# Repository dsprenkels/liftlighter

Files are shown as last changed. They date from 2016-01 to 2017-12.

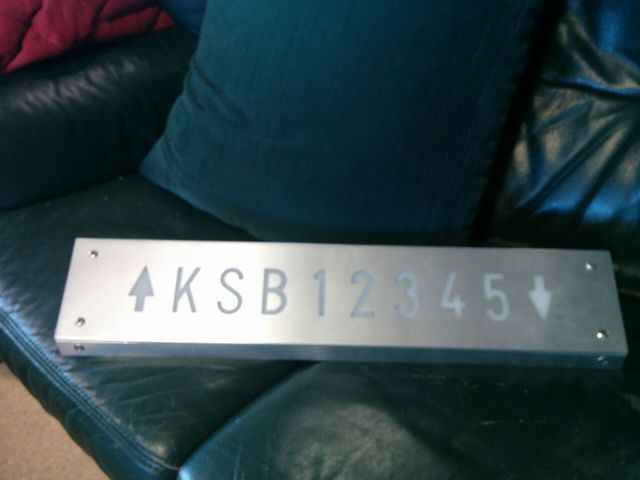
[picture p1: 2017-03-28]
photo.jpg

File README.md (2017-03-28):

# LiftLighter

I once found an old lift indicator in Radboud University's Faculty of
Science (credits to Luuk van Summeren). If you don't know what I mean,
[here is an example][photo].

The indicator has ten lights: down, 1, 2, 3, 4, 5, B, S, K and up. This
repository contains the KiCad files for the circuit board and the software
for the _Atmega8_ microcontroller.

## Components

The board (as you can see in the schematic) is reasonably modular. If you are
going to build your own setup, I recommend doing so with a 3.3V power supply
with LEDs instead of 12V lights.

For a breadboard-proof-of-concept:
- 1x Atmega8 microcontroller
- 11x LED + resistor
- 1x 32.768kHz crystal
- 2x 22 pF capacitors (for use with crystal)
- 1x pull-up resistor (30-80kΩ) for reset
- 1x control button

For a very complete setup, add:
- 1x reset button
- 1x switch or pin header w/ jumper for PD5.
- 12V setup
  * 1x 3.3V voltage regulator
  * 1x 100nF capacitor (for use with voltage regulator)
  * 1x 10μF capacitor (for use with voltage regulator)
  * 10x 12V led light + transistor + resistor (instead of LEDs)
  * 1x fuse <!-- TODO calculate threshold value -->
  * 1x 3.3V backup battery
  * 1x diode (for use with backup battery)
  * 1x diode (for prevention of backflow current)
- Pin headers (whichever amount you are going to need)

## Getting started

> If you are interested in this project, ask me personally about it. Although
  I try to keep my documentation complete and readable, I think it may be
  hard to get your setup correctly. Anyway, here goes:

I use a Raspberri Pi to flash my microcontrollers, for this I use a customized
version of the [`avrdude`] tool which uses `linuxspi` ([more info about
this][Raspberri Pi as an AVR Programmer]). If you have your own methods to
flash your microcontrollers you can just use them. In this README I assume you
will be using my method.

1. Install [`KiCad`] (I used version 4.0.3)
2. Install `gcc-avr`, `avr-libc` and **Kevin Cuzner's** [`avrdude`] tool on
   your Raspberri Pi.
3. `git clone https://github.com/dsprenkels/liftlighter.git`
4. `cd liftlighter`
5. Wire up the microcontroller and all the components on a breadboard
   according to the KiCad `liftlighter.sch` file. I recommend tweaking the
   setup, using LEDs instead of 12V lights (which allows you to ditch all the
   transistors). Parts like the 32.768kHz crystal _are_ important!
6. Connect the Raspberri Pi's GPIO pins to the microcontroller (see below).
7. `make flash`
8. Send me an e-mail, because something did not work as expected.

If all went well, the Atmega8 microcontroller should now be executing the
liftlighter

## Wire connections

All the wiring used during the normal operation of the program can be viewed
in `pcb/liftlighter.sch` using KiCad. Furthermore, a PCB layout can be found
in `pcb/liftlighter.kicad_pcb`.

To flash the microcontroller, I use my Raspberri Pi and Kevin Cuzner's
[`avrdude`] tool. When using this setup, you will have to connect the following
(physically numbered) pins:

| type | Pi  | Atmega8  |
| ---- | --- | --- |
| Vcc  | 17  |  7 & 2 |
| GND  | 20  |  8 & 22  |
| RST  | 22  |  1 (PC6) |
| MOSI | 19  | 17 (PB3) |
| MISO | 21  | 18 (PB4) |
| SCLK | 23  | 19 |

You can actually use any free GPIO pin for reset, as long as you tell `arvdude`
which one you are using [in the Makefile][reset pin].

`make fuse` calls `avrdude` and the Pi should immediately see the Atmega8. If
it does not work, check your connections. More reading about using a Raspberri
Pi to flash a microcontroller can be found [on Cuzner's blog][Raspberri Pi as
an AVR programmer]. Additionally, you may find the [datasheet for the
Atmega8][atmega8] helpful. You can also write me an email.

## Questions

Feel free to send me an email on my Github associated e-mail address.

[photo]: photo.jpg
[`KiCad`]: http://kicad-pcb.org/
[`avrdude`]: https://github.com/kcuzner/avrdude
[Raspberri Pi as an AVR programmer]: http://kevincuzner.com/2013/05/27/raspberry-pi-as-an-avr-programmer/
[reset pin]: https://github.com/dsprenkels/liftlighter/blob/master/Makefile#L9
[atmega8]: http://www.atmel.com/Images/Atmel-2486-8-bit-AVR-microcontroller-ATmega8_L_datasheet.pdf

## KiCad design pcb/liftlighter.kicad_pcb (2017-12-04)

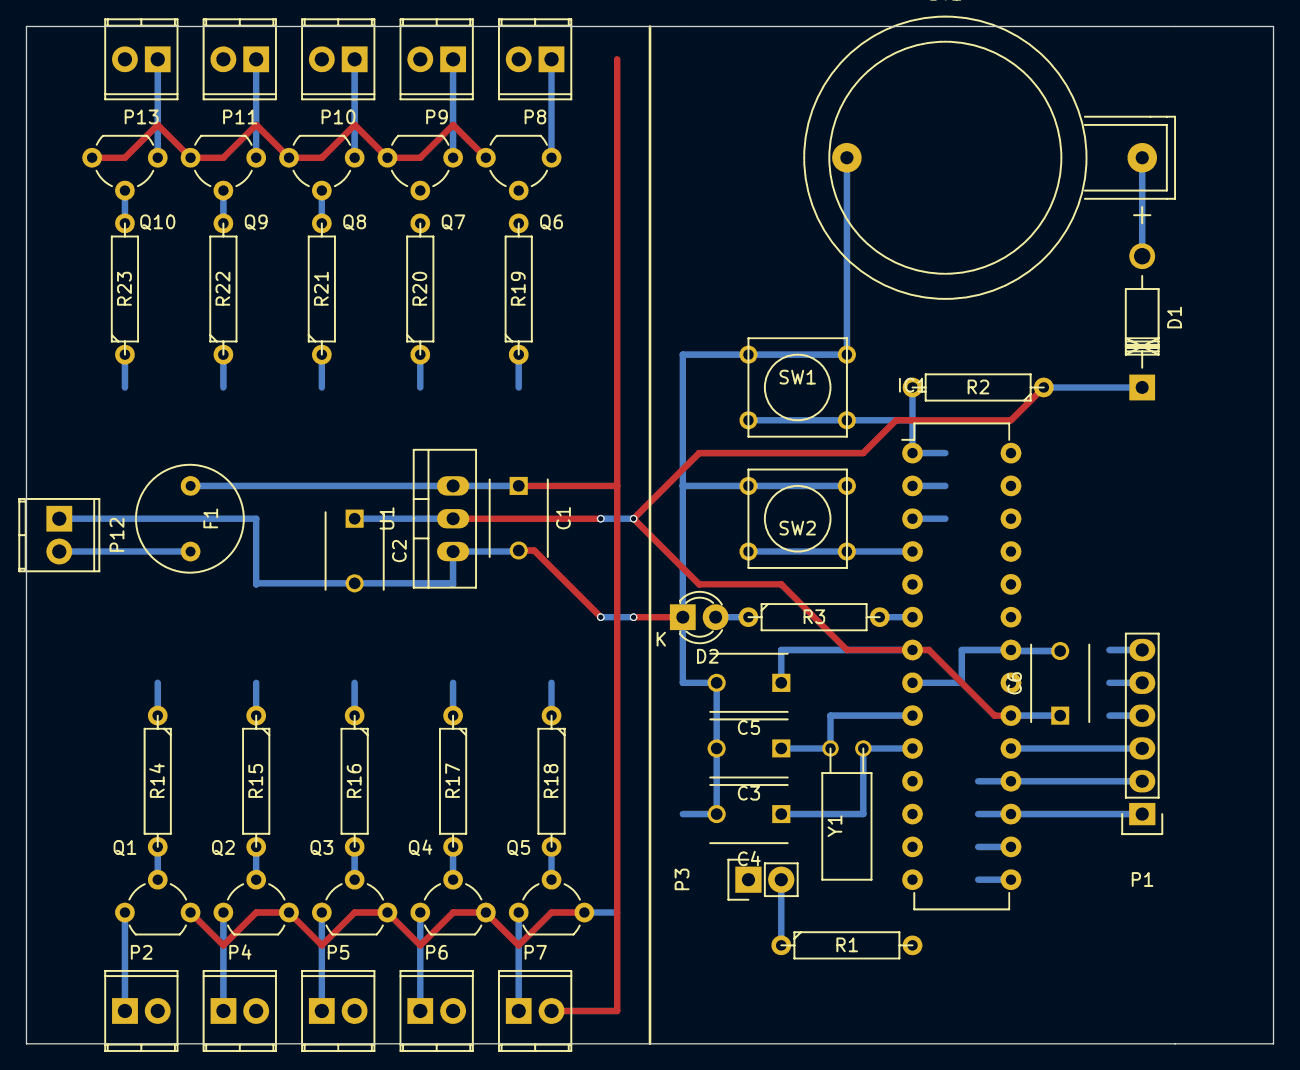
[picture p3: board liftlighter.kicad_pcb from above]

Board: 2 copper layers, 96.5 x 78.7 mm, 51 parts (0 on the bottom side), 44 nets.

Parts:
BT1: 3V; CR2032H
C1, C5, C6: 100nF; C_Disc_D6_P5
C2: 10uF; C_Disc_D6_P5
C3, C4: 22pF; C_Disc_D6_P5
D1: D; Diode_DO-41_SOD81_Horizontal_RM10
D2: LED; LED-3MM
F1: FUSE; FUSE_ROUND
IC1: ATMEGA8-P; DIP-28_W7.62mm
P1: CONN_01X06; Pin_Header_Straight_1x06
P2, P4, P5, P6, P7, P8, P9, P10, P11, P12, P13: CONN_01X02; TerminalBlock_Pheonix_MPT-2.54mm_2pol
P3: CONN_01X02; Pin_Header_Straight_1x02
Q1, Q2, Q3, Q4, Q5, Q6, Q7, Q8, Q9, Q10: BC548; TO-92_Molded_Wide
R1, R2: 50K; R4
R3: 160; R4
R14, R15, R16, R17, R18, R19, R20, R21, R22, R23: R; R4
SW1, SW2: SW_PUSH; SW_PUSH_SMALL
U1: LD1117S33TR; TO-220_Neutral123_Vertical
Y1: Crystal; Crystal_Watch

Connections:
+12V: C1.1, F1.2, P2.2, P4.2, P5.2, P6.2, P7.2, P8.2, P9.2, P10.2, P11.2, P13.2, U1.3
/a0: IC1.14, R14.1
/a1: IC1.15, R15.1
/a2: IC1.16, R16.1
/a3: IC1.17, P1.1, R17.1
/a4: IC1.18, P1.2, R18.1
/a5: IC1.19, P1.3, R19.1
/a6: IC1.23, R20.1
/a7: IC1.24, R21.1
/a8: IC1.25, R22.1
/a9: IC1.26, R23.1
GND: BT1.2, C1.2, C2.2, C3.2, C4.2, C5.2, C6.2, D2.1, IC1.8, IC1.22, P12.1, Q1.3, Q2.3, Q3.3, Q4.3, Q5.3, Q6.3, Q7.3, Q8.3, Q9.3, Q10.3, R1.2, SW1.1, SW2.2, U1.1
unnamed: BT1.1, D1.2
unnamed: C3.1, IC1.9, Y1.1
unnamed: C4.1, IC1.10, Y1.2
unnamed: D2.2, R3.1
unnamed: F1.1, P12.2
unnamed: IC1.1, P1.6, R2.2, SW1.2
unnamed: IC1.2, P1.5
unnamed: IC1.3, P1.4
unnamed: IC1.4, SW2.1
unnamed: IC1.6, R3.2
unnamed: IC1.11, P3.2, R1.1
unnamed: P2.1, Q1.1
unnamed: P4.1, Q2.1
unnamed: P5.1, Q3.1
unnamed: P6.1, Q4.1
unnamed: P7.1, Q5.1
unnamed: P8.1, Q6.1
unnamed: P9.1, Q7.1
unnamed: P10.1, Q8.1
unnamed: P11.1, Q9.1
unnamed: P13.1, Q10.1
unnamed: Q1.2, R14.2
unnamed: Q2.2, R15.2
unnamed: Q3.2, R16.2
unnamed: Q4.2, R17.2
unnamed: Q5.2, R18.2
unnamed: Q6.2, R19.2
unnamed: Q7.2, R20.2
unnamed: Q8.2, R21.2
unnamed: Q9.2, R22.2
unnamed: Q10.2, R23.2
VCC: C2.1, C5.1, C6.1, D1.1, IC1.7, IC1.20, P3.1, R2.1, U1.2

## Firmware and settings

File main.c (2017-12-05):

#define F_CPU 1000000L
#define BLOCK_BEGIN_M 45
#define BLOCK_END_M 30
#define BLOCK_ANNOUNCE_M 37
#define LONG_PRESS_DURATION 1000 /* ms */
// Location: Nijmegen, The Netherlands
#define LOCATION_LONGITUDE 51.8126
#define LOCATION_LATITUDE 5.8372

// Update the state twice per second
#define UPDATES_PER_SECOND 2.0

#include "nl_dst.h"
#include "random.h"
#include "uart.h"
#include <avr/cpufunc.h>
#include <avr/eeprom.h>
#include <avr/interrupt.h>
#include <avr/io.h>
#include <avr/sleep.h>
#include <stdbool.h>
#include <stdio.h>
#include <util/delay.h>
#include <util/eu_dst.h>
#include <time.h>

#ifdef ENABLE_WATCHDOG
#include <avr/wdt.h>
#endif /* ENABLE_WATCHDOG */


struct tm_hms {
	int8_t tm_hour;
	int8_t tm_min;
	int8_t tm_sec;
};


struct Input {
	volatile unsigned char *ddr_reg;
	const unsigned char ddr_shl;
	volatile unsigned char *pin_reg;
	const unsigned char pin_shl;
};


struct Output {
	volatile unsigned char *ddr_reg;
	const unsigned char ddr_shl;
	volatile unsigned char *port_reg;
	const unsigned char port_shl;
};

// 2 ticks per seconds, if we already tick'd this second then HALFSECOND = true
volatile bool HALFSECOND = false;

volatile enum {
	UP, DOWN, DOWN_AND_HANDLED
} CONTROL_BUTTON_STATE = UP;

// inputs and outputs
const struct Input CONTROL_BUTTON = {&DDRD, DDD2, &PIND, PIND2};
const struct Input S_SWITCH = {&DDRD, DDD5, &PIND, PIND5};
const struct Output CPUBUSY_LED = {&DDRD, DDD4, &PORTD, PD4};
const struct Output LIGHTS[] = {
	{&DDRB, PB0, &PORTB, PB0},
	{&DDRB, PB1, &PORTB, PB1},
	{&DDRB, PB2, &PORTB, PB2},
	{&DDRB, PB3, &PORTB, PB3},
	{&DDRB, PB4, &PORTB, PB4},
	{&DDRB, PB5, &PORTB, PB5},
	{&DDRC, PC0, &PORTC, PC0},
	{&DDRC, PC1, &PORTC, PC1},
	{&DDRC, PC2, &PORTC, PC2},
	{&DDRC, PC3, &PORTC, PC3}
};
const size_t LIGHT_COUNT = sizeof(LIGHTS) / sizeof(LIGHTS[0]);
volatile enum {K_OFF, K_ON, K_FLASHING} K_STATE = K_OFF;
volatile enum {
	CONTROL_OFF,
	CONTROL_HOUR, CONTROL_MINUTE, CONTROL_SECOND,
	CONTROL_DAY, CONTROL_MONTH, CONTROL_YEAR
} CONTROL_STATE = CONTROL_OFF;
volatile uint16_t CONTROL_BUTTON_PRESSED_MS = 0;

// EEPROM address of the backed up timestamp
uint32_t EEMEM TIME_BACKUP = 0xffffffff;


/* UTILITY FUNCTIONS */

static struct tm_hms tm_hms_new_hms(const uint8_t h, const uint8_t m, const uint8_t s)
{
	struct tm_hms ret;
	ret.tm_hour = h;
	ret.tm_min = m;
	ret.tm_sec = s;
	return ret;
}


static struct tm_hms tm_hms_new_hm(const uint8_t h, const uint8_t m)
{
	return tm_hms_new_hms(h, m, 0);
}


static bool tm_hms_lt(const struct tm_hms x, const struct tm_hms y)
{
	if (x.tm_hour < y.tm_hour) return true;
	if (x.tm_hour > y.tm_hour) return false;
	if (x.tm_min < y.tm_min) return true;
	if (x.tm_min > y.tm_min) return false;
	if (x.tm_sec < y.tm_sec) return true;
	return false;
}


static bool tm_hms_le(const struct tm_hms x, const struct tm_hms y)
{
	if (x.tm_hour < y.tm_hour) return true;
	if (x.tm_hour > y.tm_hour) return false;
	if (x.tm_min < y.tm_min) return true;
	if (x.tm_min > y.tm_min) return false;
	if (x.tm_sec <= y.tm_sec) return true;
	return false;
}


static struct tm_hms tm_hms_from_tm(const struct tm *in)
{
	struct tm_hms ret;
	ret.tm_hour = in->tm_hour;
	ret.tm_min = in->tm_min;
	ret.tm_sec = in->tm_sec;
	return ret;
}


static bool tm_hms_is_between(const struct tm_hms cur,
                              const struct tm_hms start,
                              const struct tm_hms end)
{
	if (tm_hms_lt(start, end)) {
		// normal
		return tm_hms_le(start, cur) && tm_hms_le(cur, end);
	} else {
		// end < start
		return tm_hms_le(start, cur) || tm_hms_le(cur, end);
	}
}


static bool flashing_is_on()
{
	return HALFSECOND;
}


static bool control_button_is_down()
{
	return (*CONTROL_BUTTON.pin_reg & (1 << CONTROL_BUTTON.pin_shl)) != 0;
}


static void printf_time(char *fmt, time_t timer)
{
	if (timer == 0) time(&timer);
	printf(fmt, ctime(&timer));
}


/* CPUBUSY_LED CONTROL */

static void cpubusy_on()
{
	*CPUBUSY_LED.port_reg |= (1 << CPUBUSY_LED.port_shl);
}


static void cpubusy_off()
{
	*CPUBUSY_LED.port_reg &= ~(1 << CPUBUSY_LED.port_shl);
}


/* LIGHT SWITCHING */

static void switch_lights(const bool lights_on[LIGHT_COUNT])
{
	size_t i;
	uint8_t maskb = 0, maskc = 0;
	uint8_t portb = 0, portc = 0;
	const struct Output *light;

	// which bits are we allowed to touch?
	for (i = 0; i < LIGHT_COUNT; i++) {
		maskb |= (uint8_t) ((LIGHTS[i].port_reg == &PORTB) << LIGHTS[i].port_shl);
		maskc |= (uint8_t) ((LIGHTS[i].port_reg == &PORTC) << LIGHTS[i].port_shl);
	}

	// build new PORT{B,C} values
	for (i = 0; i < LIGHT_COUNT; i++) {
		light = &LIGHTS[i];
		if (light->port_reg == &PORTB) {
			portb |= (uint8_t) (lights_on[i] << light->port_shl);
		}
		if (light->port_reg == &PORTC) {
			portc |= (uint8_t) (lights_on[i] << light->port_shl);
		}
	}

	// output values
	PORTB = (uint8_t) (PORTB & ~maskb) | portb;
	PORTC = (uint8_t) (PORTC & ~maskc) | portc;
}


/* LIGHT LOGIC */

static bool get_light_down_value(const struct tm *cur_tm)
{
	const struct tm_hms cur = tm_hms_from_tm(cur_tm);
	const struct tm_hms start = tm_hms_new_hm(21, 30);
	const struct tm_hms end = tm_hms_new_hm(8, 00);
	return tm_hms_is_between(cur, start, end);
}


static bool get_light_one_value(const struct tm *cur_tm)
{
	// on during the first block
	const struct tm_hms cur = tm_hms_from_tm(cur_tm);
	const struct tm_hms start = tm_hms_new_hm(8, BLOCK_BEGIN_M);
	const struct tm_hms end = tm_hms_new_hm(10, BLOCK_END_M);
	const struct tm_hms a_start = tm_hms_new_hm(8, BLOCK_ANNOUNCE_M);
	const struct tm_hms a_end = tm_hms_new_hm(8, BLOCK_BEGIN_M);

	if (tm_hms_is_between(cur, start, end)) {
		return true;
	} else if (tm_hms_is_between(cur, a_start, a_end)) {
		return flashing_is_on();
	}
	return false;
}


static bool get_light_two_value(const struct tm *cur_tm)
{
	// on during the second block
	const struct tm_hms cur = tm_hms_from_tm(cur_tm);
	const struct tm_hms start = tm_hms_new_hm(10, BLOCK_BEGIN_M);
	const struct tm_hms end = tm_hms_new_hm(12, BLOCK_END_M);
	const struct tm_hms a_start = tm_hms_new_hm(10, BLOCK_ANNOUNCE_M);
	const struct tm_hms a_end = tm_hms_new_hm(10, BLOCK_BEGIN_M);

	if (tm_hms_is_between(cur, start, end)) {
		return true;
	} else if (tm_hms_is_between(cur, a_start, a_end)) {
		return flashing_is_on();
	}
	return false;
}


static bool get_light_three_value(const struct tm *cur_tm)
{
	// on during the third block
	const struct tm_hms cur = tm_hms_from_tm(cur_tm);
	const struct tm_hms start = tm_hms_new_hm(13, BLOCK_BEGIN_M);
	const struct tm_hms end = tm_hms_new_hm(15, BLOCK_END_M);
	const struct tm_hms a_start = tm_hms_new_hm(13, BLOCK_ANNOUNCE_M);
	const struct tm_hms a_end = tm_hms_new_hm(13, BLOCK_BEGIN_M);

	if (tm_hms_is_between(cur, start, end)) {
		return true;
	} else if (tm_hms_is_between(cur, a_start, a_end)) {
		return flashing_is_on();
	}
	return false;
}


static bool get_light_four_value(const struct tm *cur_tm)
{
	// on during the fourth block
	const struct tm_hms cur = tm_hms_from_tm(cur_tm);
	const struct tm_hms start = tm_hms_new_hm(15, BLOCK_BEGIN_M);
	const struct tm_hms end = tm_hms_new_hm(17, BLOCK_END_M);
	const struct tm_hms a_start = tm_hms_new_hm(15, BLOCK_ANNOUNCE_M);
	const struct tm_hms a_end = tm_hms_new_hm(15, BLOCK_BEGIN_M);

	if (tm_hms_is_between(cur, start, end)) {
		return true;
	} else if (tm_hms_is_between(cur, a_start, a_end)) {
		return flashing_is_on();
	}
	return false;
}


static bool get_light_five_value(const struct tm *cur_tm)
{
	// opening times of the Refter
	const struct tm_hms cur = tm_hms_from_tm(cur_tm);
	const struct tm_hms start = tm_hms_new_hm(15, 0);
	const struct tm_hms end = tm_hms_new_hm(17, 0);
	return tm_hms_is_between(cur, start, end);
}


static bool get_light_b_value(const struct tm *cur_tm)
{
	// is it time for beer?
	const struct tm_hms cur = tm_hms_from_tm(cur_tm);
	const struct tm_hms start = tm_hms_new_hm(16, 0);
	const struct tm_hms end = tm_hms_new_hm(21, 0);
	return tm_hms_is_between(cur, start, end);
}


static bool get_light_k_value(const struct tm *cur_tm)
{
	return K_STATE == K_ON || (K_STATE == K_FLASHING && flashing_is_on());
}


static bool get_light_s_value(const struct tm *_)
{
	// on if we are in the southern canteen (controlled by switch)
	return (*S_SWITCH.pin_reg & (1 << S_SWITCH.pin_shl)) != 0;
}


static bool get_light_up_value(const struct tm *cur_tm)
{
	const struct tm_hms cur = tm_hms_from_tm(cur_tm);
	const struct tm_hms a_start1 = tm_hms_new_hm(8, BLOCK_ANNOUNCE_M);
	const struct tm_hms a_end1 = tm_hms_new_hm(8, BLOCK_BEGIN_M);
	const struct tm_hms a_start2 = tm_hms_new_hm(10, BLOCK_ANNOUNCE_M);
	const struct tm_hms a_end2 = tm_hms_new_hm(10, BLOCK_BEGIN_M);
	const struct tm_hms a_start3 = tm_hms_new_hm(13, BLOCK_ANNOUNCE_M);
	const struct tm_hms a_end3 = tm_hms_new_hm(13, BLOCK_BEGIN_M);
	const struct tm_hms a_start4 = tm_hms_new_hm(15, BLOCK_ANNOUNCE_M);
	const struct tm_hms a_end4 = tm_hms_new_hm(15, BLOCK_BEGIN_M);

	return tm_hms_is_between(cur, a_start1, a_end1) ||
	       tm_hms_is_between(cur, a_start2, a_end2) ||
	       tm_hms_is_between(cur, a_start3, a_end3) ||
	       tm_hms_is_between(cur, a_start4, a_end4);
}


/* CHANGING THE CURRENT TIME */

static void control_button_shortpress()
{
	time_t current_time = time(NULL);
	struct tm current_tm;

	localtime_r(&current_time, &current_tm);

	// update time figure
	switch (CONTROL_STATE) {
		case CONTROL_OFF:
			// do nothing
			return;
		case CONTROL_HOUR:
			current_tm.tm_hour = (current_tm.tm_hour + 1) % 24;
			break;
		case CONTROL_MINUTE:
			current_tm.tm_min = (current_tm.tm_min + 1) % 60;
			break;
		case CONTROL_SECOND:
			// do not add 1, but reset to minute offset
			current_tm.tm_sec = 0;
			break;
		case CONTROL_DAY:
			current_tm.tm_mday = (current_tm.tm_mday + 1) %
				month_length(1900 + (uint16_t) current_tm.tm_year,
				             current_tm.tm_mon + 1);
			break;

		case CONTROL_MONTH:
			current_tm.tm_mon = (current_tm.tm_mon + 1) % 12;
			break;
		case CONTROL_YEAR:
			if (++current_tm.tm_year >= 200) {
				current_tm.tm_year -= 100;
			}
			break;
		default:
			CONTROL_STATE = CONTROL_OFF;
			return;
	}

	// write the new system time
	set_system_time(mktime(&current_tm));
	printf_time("New time: %s\r\n", 0);
}


static void control_button_longpress()
{
	// go to the next control state
	switch (CONTROL_STATE) {
		case CONTROL_OFF:
			printf("Control mode on\r\n");
			CONTROL_STATE = CONTROL_HOUR;
			printf("Control mode: hour\r\n");
			break;
		case CONTROL_HOUR:
			CONTROL_STATE = CONTROL_MINUTE;
			printf("Control mode: minute\r\n");
			break;
		case CONTROL_MINUTE:
			CONTROL_STATE = CONTROL_SECOND;
			printf("Control mode: second\r\n");
			break;
		case CONTROL_SECOND:
			CONTROL_STATE = CONTROL_DAY;
			printf("Control mode: day\r\n");
			break;
		case CONTROL_DAY:
			CONTROL_STATE = CONTROL_MONTH;
			printf("Control mode: month\r\n");
			break;
		case CONTROL_MONTH:
			CONTROL_STATE = CONTROL_YEAR;
			printf("Control mode: year\r\n");
			break;
		default:
			CONTROL_STATE = CONTROL_OFF;
			printf("Control mode off\r\n");
			break;
	}
}

// this function assumes that interrupts are currently DISABLED
static void backup_time(uint32_t timer)
{
	printf("Backing up time... ");
	eeprom_write_dword(&TIME_BACKUP, timer);
	printf("ok\r\n");
}


// this function also assumes that interrupts are currently DISABLED
static void maybe_backup_time() {
	uint32_t timer;
	struct tm tm;

	if (HALFSECOND) return;

	time(&timer);
	gmtime_r(&timer, &tm);

	if (tm.tm_hour == 0 && tm.tm_min == 0 && tm.tm_sec == 0) {
		backup_time(timer);
	}
}

// this function dumps the current time on every minute
static void maybe_print_time() {
	uint32_t timer;
	struct tm tm;

	if (HALFSECOND) return;

	time(&timer);
	gmtime_r(&timer, &tm);
	if (tm.tm_sec == 0) {
		printf_time("Current time: %s\r\n", timer);
	}
}


/* INTERRUPT HANDLERS */

ISR(INT0_vect)
{
	// the CONTROL button is down, reset the timer
	if (CONTROL_BUTTON_STATE == UP) {
		CONTROL_BUTTON_STATE = DOWN;
	};
	CONTROL_BUTTON_PRESSED_MS = 0;
}

ISR(TIMER2_OVF_vect)
{
	if (HALFSECOND) {
		system_tick();
	}
	HALFSECOND = !HALFSECOND;
}


int my_dst(const time_t *timer, int32_t *z) {
	return ONE_HOUR;
}

/* MAINLOOP FUNCTIONS */

int console_put(char c, FILE *file)
{
	UART_transmit(c);
	return 0;
}

static void init()
{
	size_t i;
	const struct Output *light;
	uint8_t ddrb = 0, ddrc = 0, ddrd = 0;
	uint32_t timer;

	// set cpubusy led pin to output
	*CPUBUSY_LED.ddr_reg |= (uint8_t) (1 << CPUBUSY_LED.ddr_shl);
	_NOP();

	// initialize the UART console
	UART_init();
	fdevopen(console_put, NULL);
	printf("Starting liftlighter\r\n");

	// set all light pins to output
	for (i = 0; i < LIGHT_COUNT; i++) {
		light = &LIGHTS[i];
		if (light->ddr_reg == &DDRB) {
			ddrb |= (uint8_t) (1 << light->ddr_shl);
		} else if (light->ddr_reg == &DDRC) {
			ddrc |= (uint8_t) (1 << light->ddr_shl);
		} else if (light->ddr_reg == &DDRD) {
			ddrd |= (uint8_t) (1 << light->ddr_shl);
		}
	}
	DDRB |= ddrb;
	DDRC |= ddrc;
	DDRD |= ddrd;
	_NOP(); // for synchronization

	// turn on all lights to indicate startup
	const bool lights_on[] = {true, true, true, true, true,
		                      true, true, true, true, true};
	switch_lights(lights_on);

	// set CONTROL_BUTTON to input
	*CONTROL_BUTTON.ddr_reg &= (uint8_t) ~(1 << CONTROL_BUTTON.ddr_shl);
	_NOP();

	// set S_SWITCH to input
	*S_SWITCH.ddr_reg &= (uint8_t) ~(1 << S_SWITCH.ddr_shl);
	_NOP();

	// initialize the system time
	timer = eeprom_read_dword(&TIME_BACKUP);
	if (timer != 0xffffffff) {
		// Restore backup time
		printf("Restoring backup time... ");
		set_system_time(timer);
		printf("ok\r\n");
	} else {
#ifdef DEFAULT_TIME
		printf("Setting timestamp to %lu... ", DEFAULT_TIME);
		set_system_time(DEFAULT_TIME - UNIX_OFFSET);
		printf("ok\r\n");
#else /* DEFAULT_TIME */
		set_system_time(0);
#endif /* DEFAULT_TIME */
	}
	set_zone(+1 * ONE_HOUR);
	set_dst(nl_dst);
	set_position(LOCATION_LONGITUDE, LOCATION_LATITUDE);
	printf_time("Initialized time: %s\r\n", 0);

	// initialize Timer/Counter2 to measure seconds
	_delay_ms(1000); // wait for crystal to stabilize
	ASSR |= 1 << AS2; // set async clocking
	// prescaler 64 s.t. 0.5 seconds exactly overflows a 8 bit value
	TCCR2 = (1 << CS22); // set the rest to 0
	while ((ASSR & (1 << TCR2UB)) != 0) {} // wait TCCR2 to update
	TIMSK |= 1 << TOIE2; // enable overflow interrupt

	// setup the INT0 interrupt source
	MCUCR |= (1 << ISC00) | (1 << ISC01); // on rising edge
	GICR |= 1 << INT0; // enable interrupt on INT0

#ifdef ENABLE_WATCHDOG
	// enable watchdog Timer (watchdog of about 2 secs)
	WDTCR |= (1 << WDE) | (1 << WDP2) | (1 << WDP1) | (1 << WDP0);
	_NOP();
	printf("Watchdog enabled\r\n");
	wdt_reset();
#endif /* ENABLE_WATCHDOG */

	// enable global interrupt
	sei();
}


static void update_state()
{
	if (HALFSECOND) {
		return;
	}
	switch (K_STATE) {
		case K_ON:
		case K_OFF:
			// once every 5 hours (random), choose for `K` a new random state
			if (randint(1, 5*60*60) <= 1) {
				// go flashing once every 24 times (rare; once per 5 days)
				if (randint(1, 24) <= 1) {
					K_STATE = K_FLASHING;
				} else {
					K_STATE = !K_STATE;
				}
			}
			break;
		case K_FLASHING:
			// stop flashing after (on average) 100 seconds
			if (randint(1, 100) <= 1) {
				K_STATE = K_OFF;
			}
			break;
		default:
			// unreachable state, reset
			K_STATE = K_OFF;
	}
}


static void update_lights_normal(bool *lights_on, const struct tm *current_tm)
{
	lights_on[0] = get_light_up_value(current_tm);
	lights_on[1] = get_light_k_value(current_tm);
	lights_on[2] = get_light_s_value(current_tm);
	lights_on[3] = get_light_b_value(current_tm);
	lights_on[4] = get_light_one_value(current_tm);
	lights_on[5] = get_light_two_value(current_tm);
	lights_on[6] = get_light_three_value(current_tm);
	lights_on[7] = get_light_four_value(current_tm);
	lights_on[8] = get_light_five_value(current_tm);
	lights_on[9] = get_light_down_value(current_tm);
}


static void update_lights_control(bool *lights_on, const struct tm *current_tm)
{
	uint32_t fig; // figure (hour/minute/etc.)
	size_t i;

	switch (CONTROL_STATE) {
		case CONTROL_OFF:
			return;
		case CONTROL_HOUR:
			fig = current_tm->tm_hour;
			break;
		case CONTROL_MINUTE:
			fig = current_tm->tm_min;
			break;
		case CONTROL_SECOND:
			fig = current_tm->tm_sec;
			break;
		case CONTROL_DAY:
			fig = current_tm->tm_mday;
			break;
		case CONTROL_MONTH:
			fig = current_tm->tm_mon + 1; // s.t. 1 is January
			break;
		case CONTROL_YEAR:
			fig = current_tm->tm_year - 100; // s.t. 0 is equiv to 2000
			break;
		default:
			CONTROL_STATE = CONTROL_OFF;
			return;
	}

	// show the figure in binary format (flashing with 0.5 Hz)
	for (i = 0; i < LIGHT_COUNT; i++) {
		const bool flashing_on = flashing_is_on();
		const bool on = ((fig & ((uint32_t) 1 << i)) != 0);
		lights_on[LIGHT_COUNT-(i+1)] = on && flashing_on;
	}

}


static void update_lights()
{
	bool lights_on[] = {false, false, false, false, false,
	                    false, false, false, false, false};
	const time_t current_time = time(NULL);
	struct tm current_tm;

	localtime_r(&current_time, &current_tm);

	if (CONTROL_STATE != CONTROL_OFF) {
		update_lights_control(lights_on, &current_tm);
	} else {
		update_lights_normal(lights_on, &current_tm);
	}
	switch_lights(lights_on);
}


int main(void)
{
	init();
	MCUCR |= 1 << SE; // enable sleep

	do_sleep:
	sleep_cpu();

	// reset the watchdog
	#ifdef ENABLE_WATCHDOG
	wdt_reset();
	#endif /* ENABLE_WATCHDOG */

	cli(); // disable interrupts to prevent spurious INTO interrupts
	cpubusy_on(); // cpubusy on

	while (true) {
		// turn on the cpubusy light

		if (CONTROL_BUTTON_STATE == DOWN && control_button_is_down()) {
			if (CONTROL_BUTTON_PRESSED_MS >= LONG_PRESS_DURATION) {
				// trigger long press
				control_button_longpress();
				// disable the button until the next 'down' event
				CONTROL_BUTTON_STATE = DOWN_AND_HANDLED;
			} else {
				CONTROL_BUTTON_PRESSED_MS++;
				_delay_ms(1);
			}
		} else if (CONTROL_BUTTON_STATE == DOWN) {
			// button has *just* been lifted
			control_button_shortpress();
			CONTROL_BUTTON_STATE = DOWN_AND_HANDLED;
			break;
		} else {
			if (!control_button_is_down()) {
				CONTROL_BUTTON_STATE = UP;
			}

			// on each minute print the current time
			maybe_print_time();

			// if this is a day change, backup the time
			maybe_backup_time();

			// do update logic
			update_state();

			// show new light state
			update_lights();

			break;
		}
	}
	// turn off the cpubusy light
	if (CONTROL_STATE == CONTROL_OFF) cpubusy_off();
	sei();
	goto do_sleep;

	return 0;
}

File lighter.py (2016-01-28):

#!/usr/bin/env python3

import atexit
import collections
import datetime
import random
import time

from RPi import GPIO

PINS = [26, 23, 21, 19, 15, 13, 11, 7, 5, 3]
FREQ = 30


class Light(object):
    def __init__(self, cn):
        self.state = "unset"
        self.cn = cn

    def __repr__(self):
        return "pin '{}'".format(self.cn)


def decide_state_K(light, d):
    """Decide the current state for the K (random) light"""
    if light.state == "unset":
        light.state = "on" if random.randint(0, 1) else "off"
    if random.randint(1, FREQ*60*60) == 1:
        # change once per hour on avarage
        light.state = "on" if light.state == "off" else "off"


def decide_state_S(light, d):
    """Decide the current state for the S (southern canteen) light"""
    # we are currently not in de southern canteen
    light.state = "off"


def decide_state_B(light, d):
    """Decide the current state for the B (time for beer) light"""
    if 16 <= d.hour < 21:
        # it is time for beer
        light.state = "on"
    else:
        light.state = "off"


def decide_state_1(light, d):
    """Decide the current state for the 1 (first time frame) light"""
    if ((d.hour == 9) or (d.hour == 8 and d.minute >= 30) or
            (d.hour == 10 and d.minute < 30)):
        light.state = "on"
    else:
        light.state = "off"


def decide_state_2(light, d):
    """Decide the current state for the 2 (second time frame) light"""
    if ((d.hour == 11) or
            (d.hour == 10 and d.minute >= 30) or
            (d.hour == 12 and d.minute < 30)):
        light.state = "on"
    else:
        light.state = "off"


def decide_state_3(light, d):
    """Decide the current state for the 3 (third time frame) light"""
    if ((d.hour == 14) or
            (d.hour == 13 and d.minute >= 30) or
            (d.hour == 15 and d.minute < 30)):
        light.state = "on"
    else:
        light.state = "off"


def decide_state_4(light, d):
    """Decide the current state for the 4 (fourth time frame) light"""
    if ((d.hour == 16) or
            (d.hour == 14 and d.minute >= 30) or
            (d.hour == 17 and d.minute < 30)):
        light.state = "on"
    else:
        light.state = "off"


def decide_state_5(light, d):
    """Decide the current state for the 5 (fifth time frame) light"""
    if ((d.hour == 18) or
            (d.hour == 16 and d.minute >= 30) or
            (d.hour == 19 and d.minute < 30)):
        light.state = "on"
    else:
        light.state = "off"


def decide_state(light, d):
    """Decide the current state for any light"""
    noop = lambda light, d: None
    {
        "down": noop,
        "K": decide_state_K,
        "S": decide_state_S,
        "B": decide_state_B,
        "1": decide_state_1,
        "2": decide_state_2,
        "3": decide_state_3,
        "4": decide_state_4,
        "5": decide_state_5,
        "up": noop
    }[light.cn](light, d)


def main():
    cns = ["down", "K", "S", "B", "1", "2", "3", "4", "5", "up"]
    lights = collections.OrderedDict(zip(PINS, [Light(cn) for cn in cns]))

    try:
        GPIO.setmode(GPIO.BOARD)
        GPIO.setup(PINS, GPIO.OUT)
        while 1:
            d = datetime.datetime.now()
            for pin, light in lights.items():
                decide_state(light, d)
            onoff = [lights[pin].state == "on" for pin in PINS]
            GPIO.output(PINS, onoff)
            time.sleep(1.0 / FREQ)
    finally:
        GPIO.cleanup()


if __name__ == "__main__":
    main()

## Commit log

2017-03-22 add KiCad files
    [liftlighter.kicad_pcb, liftlighter.sch]
2017-03-22 Add time control functionality
    [liftlighter.kicad_pcb, liftlighter.sch]
2017-03-23 Be (a lot) stricter about types
    As we are working on a non-conventional platform, we should be
    careful about our integer sizes. For example, a default integer
    size is 16 bits, which is too small to contain our `TICK` global
    variable.
    [main.c]
2017-04-19 Increase drill hole size for TE connector
    [liftlighter.kicad_pcb]
2017-04-30 Add pull-down resistor for control button
    [liftlighter.kicad_pcb, liftlighter.sch]
2017-10-07 Remove USART and fix timing bug
    [liftlighter-B.Cu.gbr, liftlighter-B.Mask.gbr, liftlighter-B.SilkS.gbr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]
2017-12-04 Backup time every day
    [liftlighter.kicad_pcb, liftlighter.sch]
2017-12-05 Add debugging over UART
